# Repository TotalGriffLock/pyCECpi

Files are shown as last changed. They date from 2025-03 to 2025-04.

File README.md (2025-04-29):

# pyCECpi - pyCEC on a pi
Building a Raspberry Pi Zero into a robust HDMI-CEC IP interface to make a non-IoT TV into a controllable TV

# What?
There are some commercially available HDMI-CEC to IP interfaces for things like Control4, Crestron, etc. They cost hundreds of pounds/dollars. In the same universe, Home Assistant and Raspberry Pis exist. Surely, the expensive commercial offerings are not the only choice? Can I build a small box to go on the back of the TV to provide this kind of functionality? Also, my TV has limited HDMI ports - I don't want to lose a whole HDMI input just to add this feature, it needs to pass HDMI through

# Requirements
* Small form factor, must hide behind TV  
* HDMI-CEC controllable over IP, for integration into automation services (e.g. Home Assistant)  
* Small display screen to see status at a glance, for troubleshooting  
* HDMI passthrough, so the device does not monopolise an HDMI input - my TV only has 3 and I use them all!  
* Cheaper than existing commercially available options

# First prototype - green board


# Shopping list - Prices are UK £ sterling at the time of writing
Raspberry Pi Zero W (or Zero 2 W) - without presoldered headers £14.40 from thepihut + £3.90 shipping  
SD card for Raspberry Pi OS £6.90 for a 32GB Sandisk from Amazon, realistically this probably fits on a 4GB if you use Rasbian Pi OS Lite  
Adafruit PiOLED £14.10 from thepihut  
2x6 2.5mm pin header - a 40 pin header from the pihut is £1, you can make 6 from that, so £0.17  
3 x M2.5 16mm screws - £3.79 from eBay - cheaper in bulk  
1 x M2.5 6mm screw  
4 x M2.5 threaded inserts - £7.99 for 100 on amazon - £0.24 for 3  
1 x Mini-HDMI solderable breakout connector like https://www.aliexpress.com/item/1005006271343149.html - £4.16 for 5 delivered from aliexpress, so £0.84 each  
Some short lengths of wire, 26AWG is probably fine  
According to Cura, 23g of PLA - 1kg of PLA from the Creality store at the moment is £15 delivered so the PLA is roughly £0.35  
1 x HDMI to HDMI (preferably female to female, no pin header) breakout board such as one of these:  
* PURPLE BOARD https://www.aliexpress.com/item/1005006160781514.html - £5.71 delivered from aliexpress  
* GREEN BOARD https://www.amazon.co.uk/HDMI-Male-Connector-Breakout-Board/dp/B0B3792QC9  

TOTAL SO FAR £50.50  

# A Note on HDMI Boards
There are 2 types of HDMI breakout + passthrough boards linked here, purple and green. The dimensions are different, and the green boards tend to be a bit skewed / off centre. The STL design files accommodate for this by having quite loose tolerances around the board and where the HDMI ports sit. The green board is much easier to get, so I anticipate you'd probably use this. I think the purple board is the neater solution.  

# Tools required
3d Printer  
Soldering Iron  
Screwdriver  

# Software required
pyCEC from https://github.com/konikvranik/pyCEC  
my updated pycec.service systemd service file from this repo  
pystats.py clearoled.py and pystats.service from this repo - pystats.py is based on the Adafruit script provided with the oled screen, available at https://learn.adafruit.com/adafruit-pioled-128x32-mini-oled-for-raspberry-pi/usage  

# Steps
Assembly is a little fiddly but it makes for what I think is a very slick form factor  
Print the .stl files from this repo (in the STL folder)  
If you would like to edit the design, the Tinkercad URL is https://www.tinkercad.com/things/1sP1Ou0873z-rpi-hdmi-cec-case-v3-public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   
Solder the 3x2 pin header to pins 1-6 on the Pi  
Use your soldering iron to melt 3 threaded inserts into the case and 1 into the frame  
Fit the screen in to the case first, fit the HDMI breakout onto the frame, fit the frame into the case, then fit the pi on top of the frame  
Use the Raspberry pi imager to get your OS onto the SD card with your wifi details set, and boot up the pi  
Update your OS!  
install pyCEC as per the instructions in [konikvranik's repo ](https://github.com/konikvranik/pyCEC) 
Install the systemd and psutil python library  
```
sudo apt install python3-systemd python3-psutil
```
copy pycec.service from this repo into /etc/systemd/service
```
sudo curl -JLo /etc/systemd/service/pycec.service https://raw.githubusercontent.com/TotalGriffLock/pyCECpi/refs/heads/main/etc/systemd/system/pycec.service
```
copy pystats.service from this repo into /etc/systemd/service 
```
sudo curl -JLo /etc/systemd/service/pystats.service https://raw.githubusercontent.com/TotalGriffLock/pyCECpi/refs/heads/main/etc/systemd/system/pystats.service
```
copy pystats.py and clearoled.py into /usr/local/bin and make sure they are marked executable  
```
sudo curl -JLo /usr/local/bin/pystats.py https://raw.githubusercontent.com/TotalGriffLock/pyCECpi/refs/heads/main/usr/local/bin/pystats.py
sudo curl -JLo /usr/local/bin/clearoled.py https://raw.githubusercontent.com/TotalGriffLock/pyCECpi/refs/heads/main/usr/local/bin/clearoled.py
sudo chmod +x /usr/local/bin/*.py
```
Enable the new services
```
sudo systemctl daemon-reload
sudo systemctl enable pycec.service  
sudo systemctl enable pystats.service
```
Probably do some iptables to make sure only appropriate hosts can communicate with your pyCEC instance, something like:  
```
sudo apt install iptables-persistent
sudo iptables -I INPUT 1 -m tcp -p tcp --dport 9526 -m comment --comment "Deny access to pyCEC" -j DROP
sudo iptables -I INPUT 1 --source <homeassistantip> -m tcp -p tcp --dport 9526 -m comment --comment "Permit HomeAssistant to pyCEC" -j ACCEPT
sudo iptables-save | sudo tee /etc/iptables/rules.v4 > /dev/null
```
It is not well documented but you can create /etc/pycec.conf with the format:  
```
[DEFAULT]
host=1.2.3.4 # This is the IP of the pi to listen on, in case your pi has multiple network interfaces
port=9526    # This is the port to listen on
```
reboot!  

# Final Thoughts
There are loads of ways this could be smaller, cheaper, and simpler. 
* You can split HDMI-CEC directly into GPIO on the RPI, but that requires a kernel overlay, which must be maintained to stay in line with the kernel version. This route could get rid of the mini-hdmi breakout
* You don't need the oled screen, I just really like it. The case could be considerably thinner without it, reducing footprint. The screen is also 30% of the total cost.
* If I didn't require HDMI pass through, it could just be a bare RPI, and be loads smaller and simpler.
* I could just buy a new TV that supports IoT (e.g. Samsung's SmartThings), or a TV with more HDMI inputs and save all the hassle.
* It is tempting to power the pyCECpi directly from the USB port on your TV. Be wary of how long that port supplies power, after the TV has gone into standby.

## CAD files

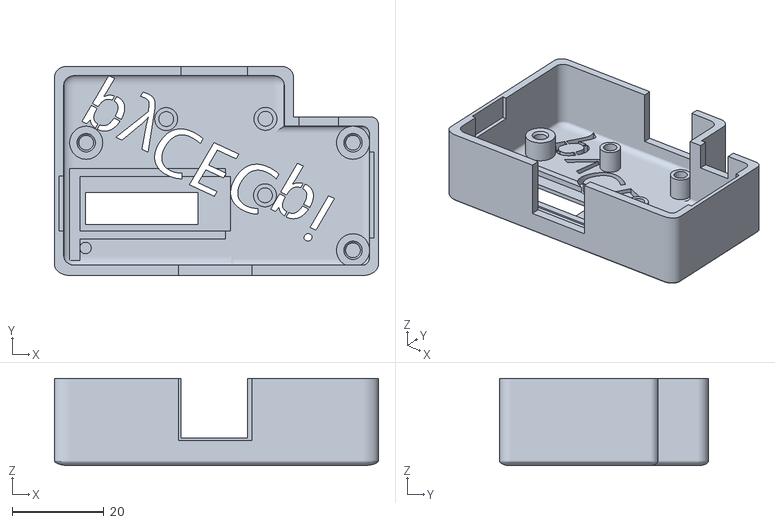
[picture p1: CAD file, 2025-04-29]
STL/Case Upper.stl
70.5 x 45.5 x 19.0

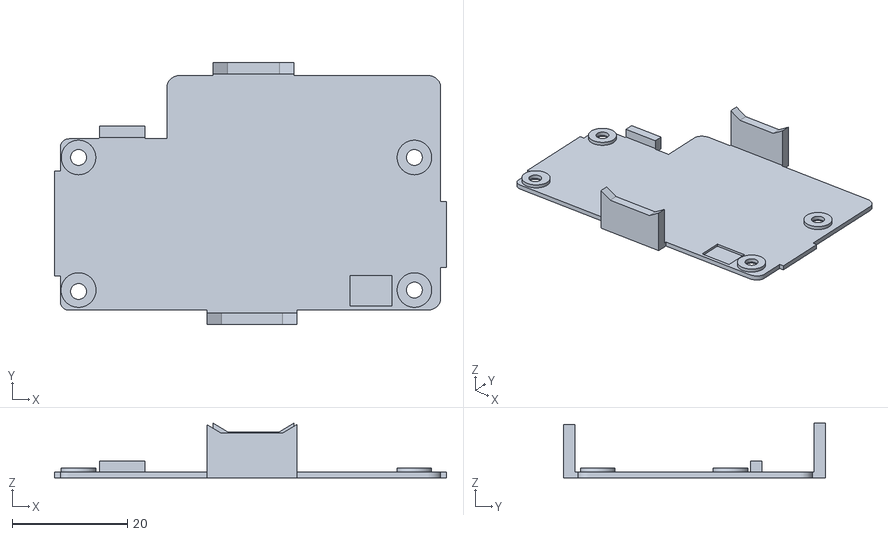
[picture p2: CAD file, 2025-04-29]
STL/Case Lower.stl
68.0 x 45.5 x 9.50

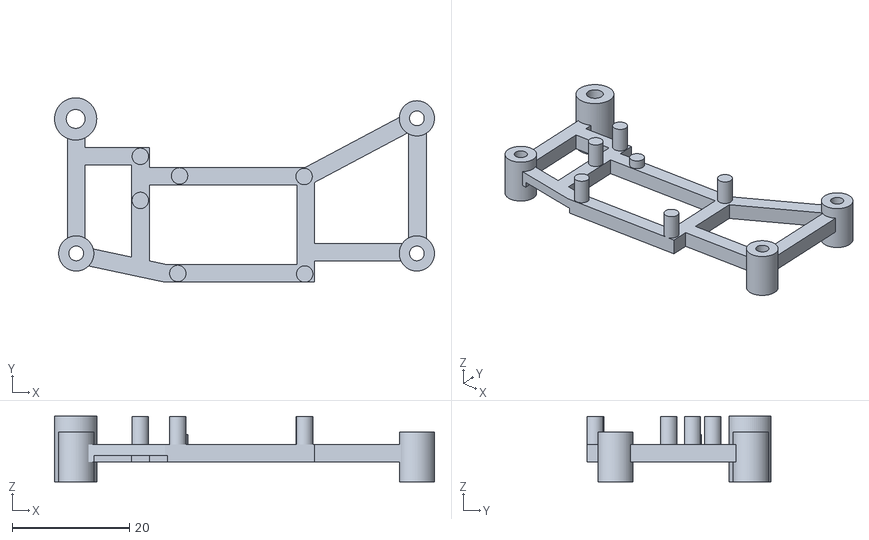
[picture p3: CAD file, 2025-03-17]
STL/Frame Inner.stl
64.7 x 31.4 x 11.2

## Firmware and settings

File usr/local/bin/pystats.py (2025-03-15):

#!/usr/bin/env python3
# SPDX-FileCopyrightText: 2017 Tony DiCola for Adafruit Industries
# SPDX-FileCopyrightText: 2017 James DeVito for Adafruit Industries
# SPDX-License-Identifier: MIT
# Additions for the pyCECpi project, see https://github.com/TotalGriffLock/pyCECpi

# This example is for use on (Linux) computers that are using CPython with
# Adafruit Blinka to support CircuitPython libraries. CircuitPython does
# not support PIL/pillow (python imaging library)!

import time
import subprocess
import select
import textwrap
import re
import psutil
from systemd import journal
from board import SCL, SDA
import busio
from PIL import Image, ImageDraw, ImageFont
import adafruit_ssd1306


# Create the I2C interface.
i2c = busio.I2C(SCL, SDA)

# Create the SSD1306 OLED class.
# The first two parameters are the pixel width and pixel height.  Change these
# to the right size for your display!
disp = adafruit_ssd1306.SSD1306_I2C(128, 32, i2c)

# Clear display.
disp.fill(0)
disp.show()

# Create blank image for drawing.
# Make sure to create image with mode '1' for 1-bit color.
width = disp.width
height = disp.height
image = Image.new("1", (width, height))

# Get drawing object to draw on image.
draw = ImageDraw.Draw(image)

# Draw a black filled box to clear the image.
draw.rectangle((0, 0, width, height), outline=0, fill=0)

# Draw some shapes.
# First define some constants to allow easy resizing of shapes.
padding = -2
top = padding
bottom = height - padding
# Move left to right keeping track of the current x position for drawing shapes.
x = 0


# Load default font.
font = ImageFont.load_default()

# Alternatively load a TTF font.  Make sure the .ttf font file is in the
# same directory as the python script!
# Some other nice fonts to try: http://www.dafont.com/bitmap.php
# font = ImageFont.truetype('/usr/share/fonts/truetype/dejavu/DejaVuSans.ttf', 9)


# systemd bits
j = journal.Reader()
j.seek_tail()
j.add_match(_SYSTEMD_UNIT='pycec.service')
j.get_previous()

# paging, start on page 1
showpage = 1

while True:
    journalstr1 = ""
    journalstr2 = ""
    wraptext = list()
    # See if we have a new journal message to display
    event = j.wait(1)
    if event == journal.APPEND:
      # We do, we should display this instead
      for entry in j:
        if not "poll" in entry['MESSAGE']:
          draw.rectangle((0, 0, width, height), outline=0, fill=0)
          # First split off the timestamp, this will be the 1st line to display
          split1 = entry['MESSAGE'].split(',',1)
          # Then split the message up by dashes - pyCEC outputs logs using a dash delimiter
          if len(split1) > 1:
            split2 = split1[1].split('- ',2)
            # Now wordwrap it so that it fits nicely on the screen
            wraptext = textwrap.fill(split2[2],20).split('\n', 3)
          else:
            wraptext.append("")
          # Draw the text on the oled screen
          # If it's longer than 3 lines it will get truncated
          # Check the lines exist before trying to display them
          draw.text((x, top + 0), split1[0], font=font, fill=255)
          draw.text((x, top + 8), wraptext[0], font=font, fill=255)
          if len(wraptext) > 1:
            draw.text((x, top + 16), wraptext[1], font=font, fill=255)
          if len(wraptext) > 2:
            draw.text((x, top + 24), wraptext[2], font=font, fill=255)
          disp.image(image)
          disp.show()
          time.sleep(0.3)
    elif showpage == 2:
      cmd = "iwgetid -r"
      ssid = subprocess.check_output(cmd, shell=True).decode("utf-8")
      cmd = "hostname -I | cut -d' ' -f1"
      IP = subprocess.check_output(cmd, shell=True).decode("utf-8")
      for process in psutil.process_iter():
        cmdline = process.cmdline()
        if "/usr/local/bin/pycec" in cmdline:
          cmd = "journalctl --boot -u pycec | grep Serv | tail -n1"
          journalstr = subprocess.check_output(cmd, shell=True).decode("utf-8")
          split1 = journalstr.split('- ',2)
          split2 = re.search("'(.+)', (\d+)", split1[2])
          journalstr1 = "pyCEC is listening on"
          journalstr2 = split2.group(1) + ":" + split2.group(2)
      if len(journalstr1) == 0:
        journalstr1 = ""
        journalstr2 = "pyCEC is NOT running!"
      # Blank the screen and write four lines of text.
      draw.rectangle((0, 0, width, height), outline=0, fill=0)
      draw.text((x, top + 0), "SSID: " + ssid, font=font, fill=255)
      draw.text((x, top + 8), "IP: " + IP, font=font, fill=255)
      draw.text((x, top + 16), journalstr1, font=font, fill=255)
      draw.text((x, top + 24), journalstr2, font=font, fill=255)

      # Display image.
      disp.image(image)
      disp.show()
      time.sleep(5)
      showpage = 1

    else:
      # Shell scripts for system monitoring from here:
      # https://unix.stackexchange.com/questions/119126/command-to-display-memory-usage-disk-usage-and-cpu-load
      cmd = 'cut -f 1 -d " " /proc/loadavg'
      CPU = subprocess.check_output(cmd, shell=True).decode("utf-8")
      cmd = "free -m | awk 'NR==2{printf \"Mem: %s/%s MB %.2f%%\", $3,$2,$3*100/$2 }'"
      MemUsage = subprocess.check_output(cmd, shell=True).decode("utf-8")
      cmd = 'df -h | awk \'$NF=="/"{printf "Disk: %d/%d GB  %s", $3,$2,$5}\''
      Disk = subprocess.check_output(cmd, shell=True).decode("utf-8")
      for process in psutil.process_iter():
        cmdline = process.cmdline()
        if "/usr/local/bin/pycec" in cmdline:
          journalstr2 = "pyCEC PID: " + str(process.pid)
      if len(journalstr2) == 0:
        journalstr2 = "pyCEC is NOT running!"

      # Blank the screen and write four lines of text.
      draw.rectangle((0, 0, width, height), outline=0, fill=0)
      draw.text((x, top + 0), "CPU load: " + CPU, font=font, fill=255)
      draw.text((x, top + 8), MemUsage, font=font, fill=255)
      draw.text((x, top + 16), Disk, font=font, fill=255)
      draw.text((x, top + 24), journalstr2, font=font, fill=255)

      # Display image.
      disp.image(image)
      disp.show()
      time.sleep(5)
      showpage = 2

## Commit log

2025-03-15 Add files via upload
    Uploaded V2 of the case
    [Case Lower.stl, Case Upper.stl, Frame Inner.stl]
2025-03-15 Create clearoled.py
    A script to clear the OLED screen on shutdown (in case the pi stays powered)
2025-03-15 Update pystats.py
    Added missing double quote
    [pystats.py]
2025-03-15 Update pystats.py
    Fix process tracking and string parsing so the script doesn't crash when pyCEC restarts
    [pystats.py]
2025-03-15 Update pystats.py
    A few more bugfixes
    [pystats.py]
2025-03-15 Update pystats.py
    Add pyCEC PID to page 1
2025-03-17 Add files via upload
    Updated case design with smaller tolerances
    [Case Lower.stl, Case Upper.stl, Frame Inner.stl]
2025-03-17 Add files via upload
    Correct a mistake in STL file
    [Case Upper.stl]
2025-03-17 Update README.md
    Correct pricing of PLA following new case design
2025-03-18 Update README.md
    Clarify screw lengths
2025-04-05 Update README.md
    Clarified screw lengths (again)
2025-04-29 Add files via upload
    Final versions of the 'green board' style.
    [Case Lower.stl, Case Upper.stl]
2025-04-29 Update README.md
    Updated prototype image
2025-04-29 Update README.md
    Added notes about HDMI boards
2025-04-29 Update README.md
    Formatting around the different board types
